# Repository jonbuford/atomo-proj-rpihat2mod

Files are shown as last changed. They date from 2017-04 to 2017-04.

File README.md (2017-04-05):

# atomo-proj-rpihat2mod
Raspberry Pi HAT Compatible 2 Module Designs

This design is using a KE02 44-pin microcontroller as an IO expander and stand-alone controller for a 2 IO module Atomo Controller Connector board. There are two versions, one with a 34-pin Power module and another that is only for powering by the Raspberry Pi.

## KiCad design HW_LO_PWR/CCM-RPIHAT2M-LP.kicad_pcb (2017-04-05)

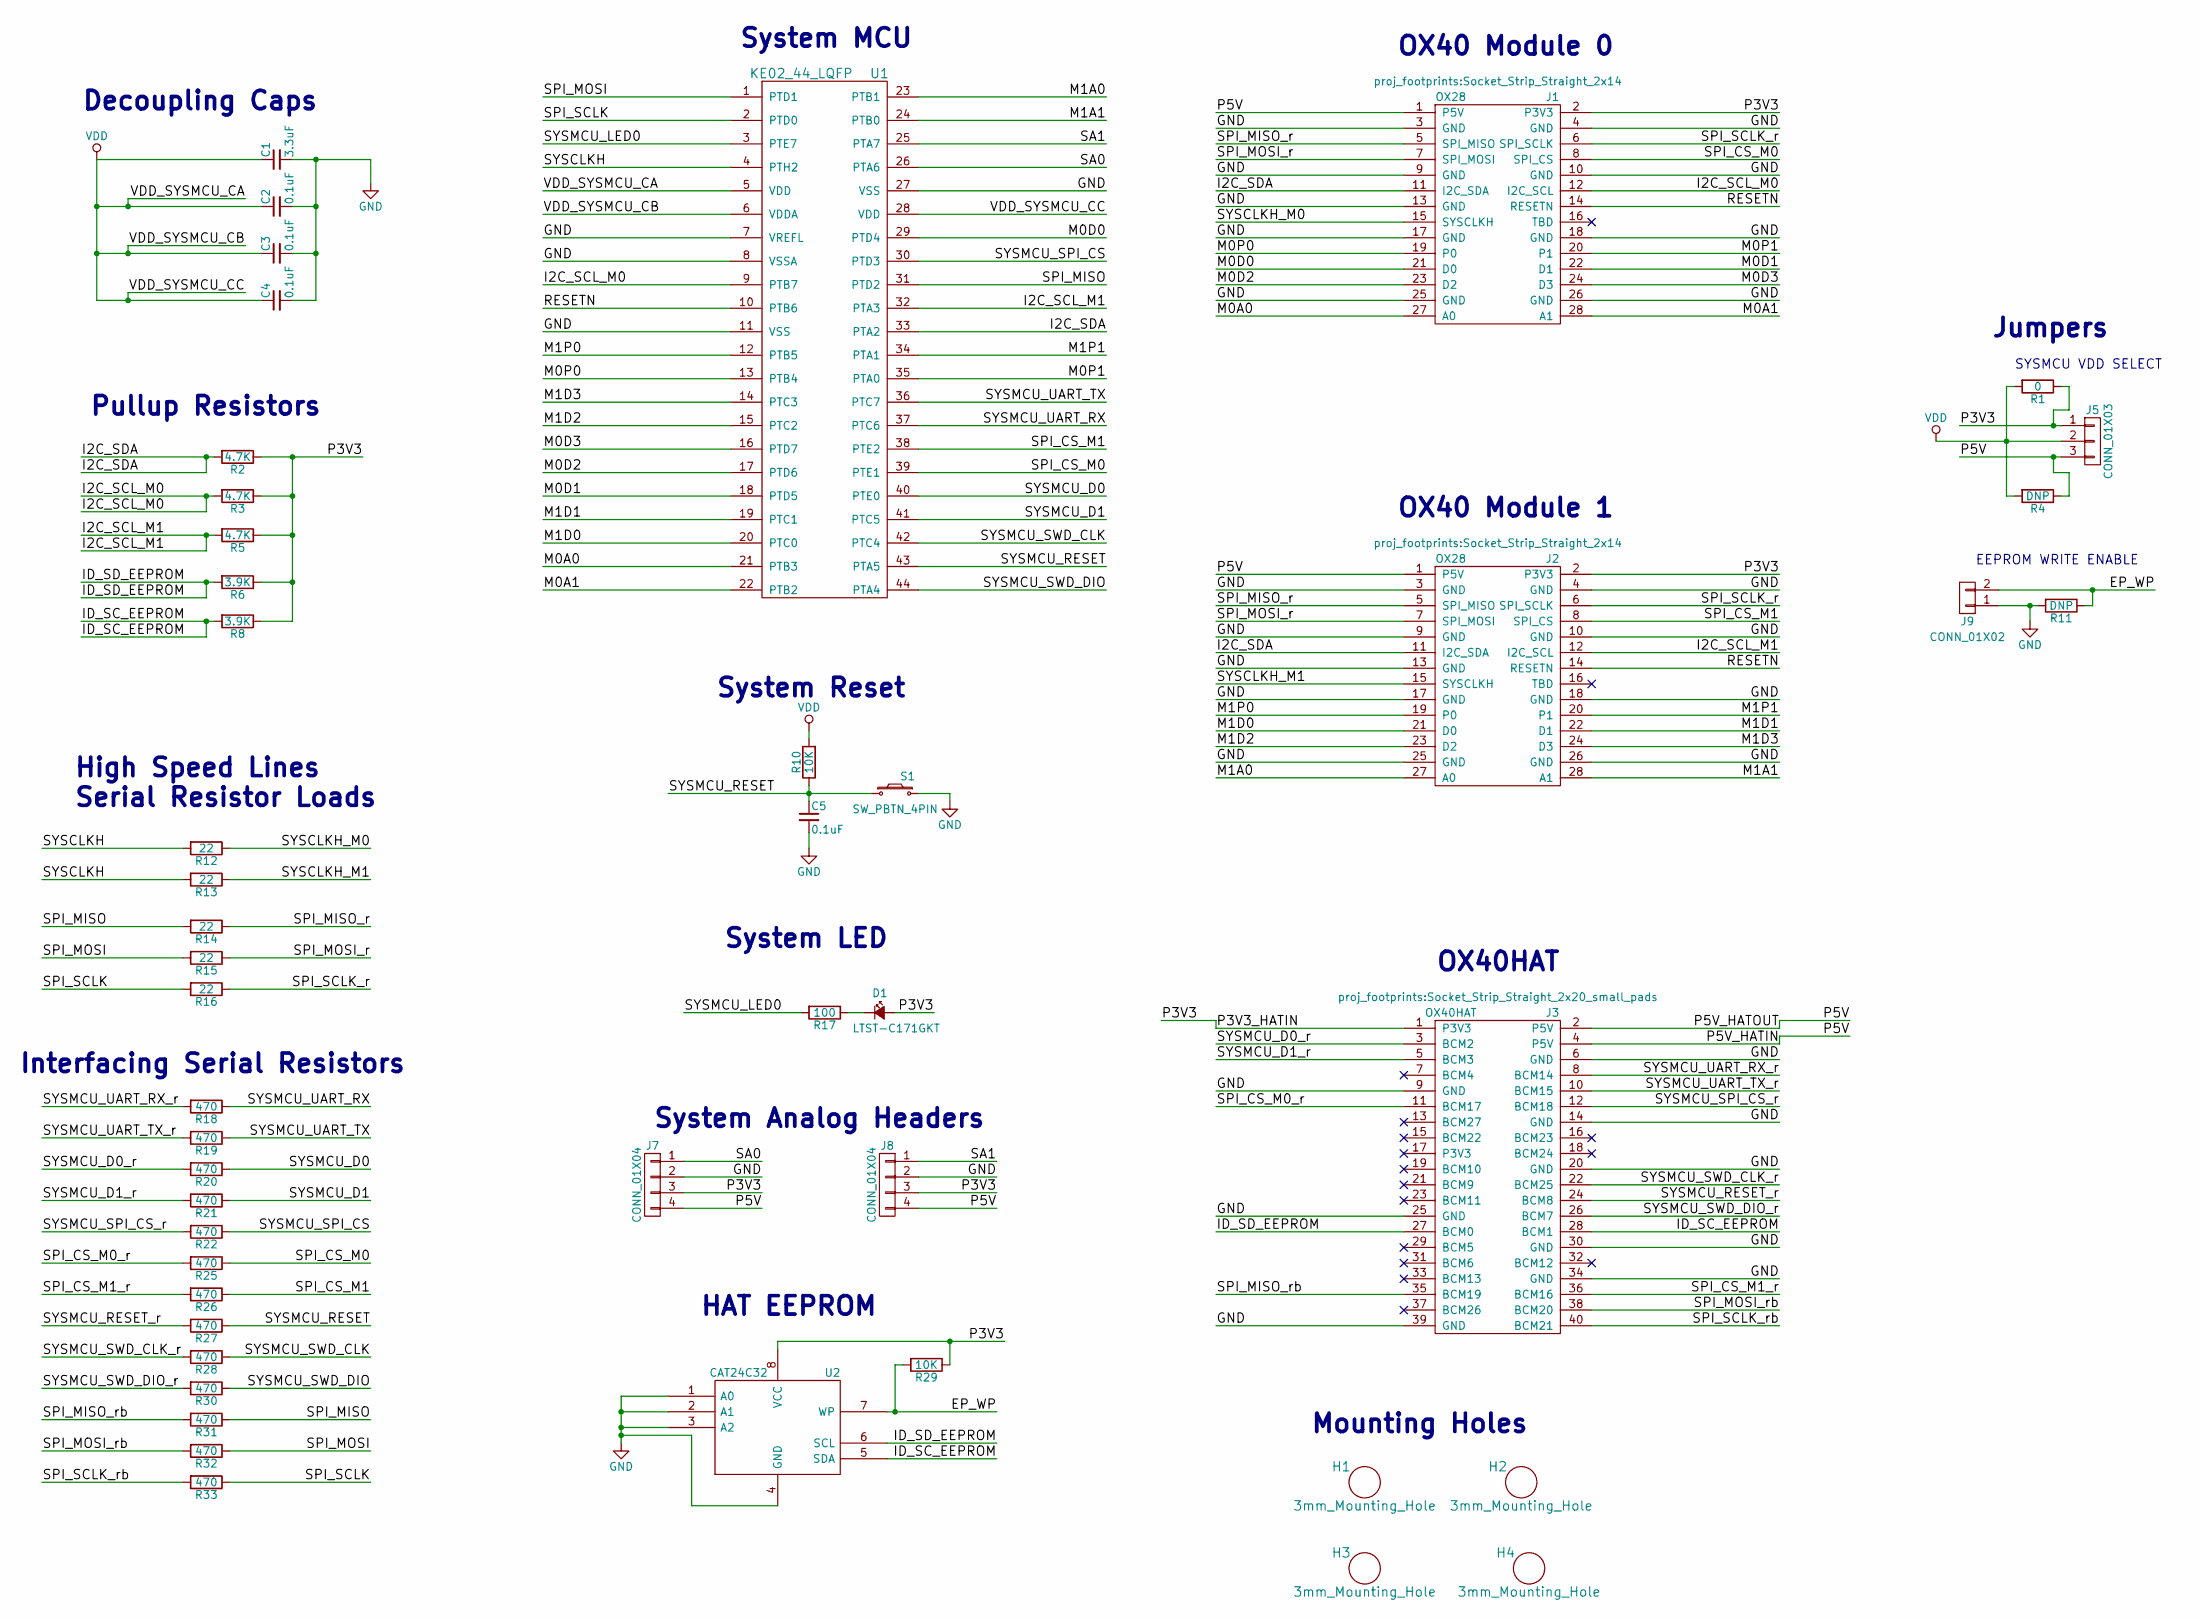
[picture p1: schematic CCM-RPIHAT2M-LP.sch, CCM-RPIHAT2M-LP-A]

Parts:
C1: 3.3uF; C_0603_HandSoldering; MPN GRM155R71H104ME14D
C2, C3, C4, C5: 0.1uF; C_0603_HandSoldering; MPN GRM155R71H104ME14D
D1: LTST-C171GKT; LED_0805
H1, H2, H3, H4: 3mm_Mounting_Hole; NPTH_3mm_ID
J1, J2: OX28; Socket_Strip_Straight_2x14
J3: OX40HAT; Socket_Strip_Straight_2x20_small_pads
J5: CONN_01X03; Pin_Header_Straight_1x03
J7, J8: CONN_01X04; Pin_Header_Straight_1x04
J9: CONN_01X02; Pin_Header_Straight_1x02
R1: 0; R_0805_HandSoldering; MPN RC0402JR-0722RL
R2, R3, R5: 4.7K; R_0603_HandSoldering; MPN RC0402JR-0722RL
R4, R11: DNP; R_0805_HandSoldering; MPN RC0402JR-0722RL
R6, R8: 3.9K; R_0603_HandSoldering; MPN RC0402JR-0722RL
R10, R29: 10K; R_0603_HandSoldering; MPN RC0402JR-0722RL
R12, R13, R14, R15, R16: 22; R_0603_HandSoldering; MPN RC0402JR-0722RL
R17: 100; R_0603_HandSoldering; MPN RC0402JR-0722RL
R18, R19, R20, R21, R22, R25, R26, R27, R28, R30, R31, R32, R33: 470; R_0603_HandSoldering; MPN RC0402JR-0722RL
S1: SW_PBTN_4PIN; SMT_6MM_Tact_SW
U1: KE02_44_LQFP; LQFP_44
U2: CAT24C32; SOIC-8

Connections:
/EP_WP: J9.2, R11.1, R29.2, U2.7 (WP)
/I2C_SCL_M0: J1.12 (I2C_SCL), R3.2, U1.9 (PTB7)
/I2C_SCL_M1: J2.12 (I2C_SCL), R5.2, U1.32 (PTA3)
/I2C_SDA: J1.11 (I2C_SDA), J2.11 (I2C_SDA), R2.2, U1.33 (PTA2)
/ID_SC_EEPROM: J3.28 (BCM1), R8.2, U2.5 (SDA)
/ID_SD_EEPROM: J3.27 (BCM0), R6.2, U2.6 (SCL)
/M0A0: J1.27 (A0), U1.21 (PTB3)
/M0A1: J1.28 (A1), U1.22 (PTB2)
/M0D0: J1.21 (D0), U1.29 (PTD4)
/M0D1: J1.22 (D1), U1.18 (PTD5)
/M0D2: J1.23 (D2), U1.17 (PTD6)
/M0D3: J1.24 (D3), U1.16 (PTD7)
/M0P0: J1.19 (P0), U1.13 (PTB4)
/M0P1: J1.20 (P1), U1.35 (PTA0)
/M1A0: J2.27 (A0), U1.23 (PTB1)
/M1A1: J2.28 (A1), U1.24 (PTB0)
/M1D0: J2.21 (D0), U1.20 (PTC0)
/M1D1: J2.22 (D1), U1.19 (PTC1)
/M1D2: J2.23 (D2), U1.15 (PTC2)
/M1D3: J2.24 (D3), U1.14 (PTC3)
/M1P0: J2.19 (P0), U1.12 (PTB5)
/M1P1: J2.20 (P1), U1.34 (PTA1)
/P3V3: D1.2 (A), J1.2 (P3V3), J2.2 (P3V3), J3.1 (P3V3), J5.1, J7.3, J8.3, R1.1, R2.1, R3.1, R5.1, R6.1, R8.1, R29.1, U2.8 (VCC)
/P5V: J1.1 (P5V), J2.1 (P5V), J3.2 (P5V), J3.4 (P5V), J5.3, J7.4, J8.4, R4.1
/RESETN: J1.14 (RESETN), J2.14 (RESETN), U1.10 (PTB6)
/SA0: J7.1, U1.26 (PTA6)
/SA1: J8.1, U1.25 (PTA7)
/SPI_CS_M0: J1.8 (SPI_CS), R25.1, U1.39 (PTE1)
/SPI_CS_M0_r: J3.11 (BCM17), R25.2
/SPI_CS_M1: J2.8 (SPI_CS), R26.1, U1.38 (PTE2)
/SPI_CS_M1_r: J3.36 (BCM16), R26.2
/SPI_MISO: R14.2, R31.1, U1.31 (PTD2)
/SPI_MISO_r: J1.5 (SPI_MISO), J2.5 (SPI_MISO), R14.1
/SPI_MISO_rb: J3.35 (BCM19), R31.2
/SPI_MOSI: R15.2, R32.1, U1.1 (PTD1)
/SPI_MOSI_r: J1.7 (SPI_MOSI), J2.7 (SPI_MOSI), R15.1
/SPI_MOSI_rb: J3.38 (BCM20), R32.2
/SPI_SCLK: R16.2, R33.1, U1.2 (PTD0)
/SPI_SCLK_r: J1.6 (SPI_SCLK), J2.6 (SPI_SCLK), R16.1
/SPI_SCLK_rb: J3.40 (BCM21), R33.2
/SYSCLKH: R12.2, R13.2, U1.4 (PTH2)
/SYSCLKH_M0: J1.15 (SYSCLKH), R12.1
/SYSCLKH_M1: J2.15 (SYSCLKH), R13.1
/SYSMCU_D0: R20.1, U1.40 (PTE0)
/SYSMCU_D0_r: J3.3 (BCM2), R20.2
/SYSMCU_D1: R21.1, U1.41 (PTC5)
/SYSMCU_D1_r: J3.5 (BCM3), R21.2
/SYSMCU_LED0: R17.2, U1.3 (PTE7)
/SYSMCU_RESET: C5.1, R10.1, R27.1, S1.1, S1.2, U1.43 (PTA5)
/SYSMCU_RESET_r: J3.24 (BCM8), R27.2
/SYSMCU_SPI_CS: R22.1, U1.30 (PTD3)
/SYSMCU_SPI_CS_r: J3.12 (BCM18), R22.2
/SYSMCU_SWD_CLK: R28.1, U1.42 (PTC4)
/SYSMCU_SWD_CLK_r: J3.22 (BCM25), R28.2
/SYSMCU_SWD_DIO: R30.1, U1.44 (PTA4)
/SYSMCU_SWD_DIO_r: J3.26 (BCM7), R30.2
/SYSMCU_UART_RX: R18.1, U1.37 (PTC6)
/SYSMCU_UART_RX_r: J3.8 (BCM14), R18.2
/SYSMCU_UART_TX: R19.1, U1.36 (PTC7)
/SYSMCU_UART_TX_r: J3.10 (BCM15), R19.2
GND: C1.2, C2.2, C3.2, C4.2, C5.2, J1.3 (GND), J1.4 (GND), J1.9 (GND), J1.10 (GND), J1.13 (GND), J1.17 (GND), J1.18 (GND), J1.25 (GND), J1.26 (GND), J2.3 (GND), J2.4 (GND), J2.9 (GND), J2.10 (GND), J2.13 (GND), J2.17 (GND), J2.18 (GND), J2.25 (GND), J2.26 (GND), J3.6 (GND), J3.9 (GND), J3.14 (GND), J3.20 (GND), J3.25 (GND), J3.30 (GND), J3.34 (GND), J3.39 (GND), J7.2, J8.2, J9.1, R11.2, S1.3, S1.4, U1.7 (VREFL), U1.8 (VSSA), U1.11 (VSS), U1.27 (VSS), U2.1 (A0), U2.2 (A1), U2.3 (A2), U2.4 (GND)
unnamed: D1.1 (K), R17.1
VDD: C1.1, C2.1, C3.1, C4.1, J5.2, R1.2, R4.2, R10.2, U1.5 (VDD), U1.6 (VDDA), U1.28 (VDD)

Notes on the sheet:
OX40 Module 1
OX40 Module 0
Decoupling Caps
Jumpers
SYSMCU VDD SELECT
EEPROM WRITE ENABLE
Pullup Resistors
HAT EEPROM
System Analog Headers
System LED
System Reset
Interfacing Serial Resistors
High Speed Lines Serial Resistor Loads
Mounting Holes
OX40HAT
System MCU

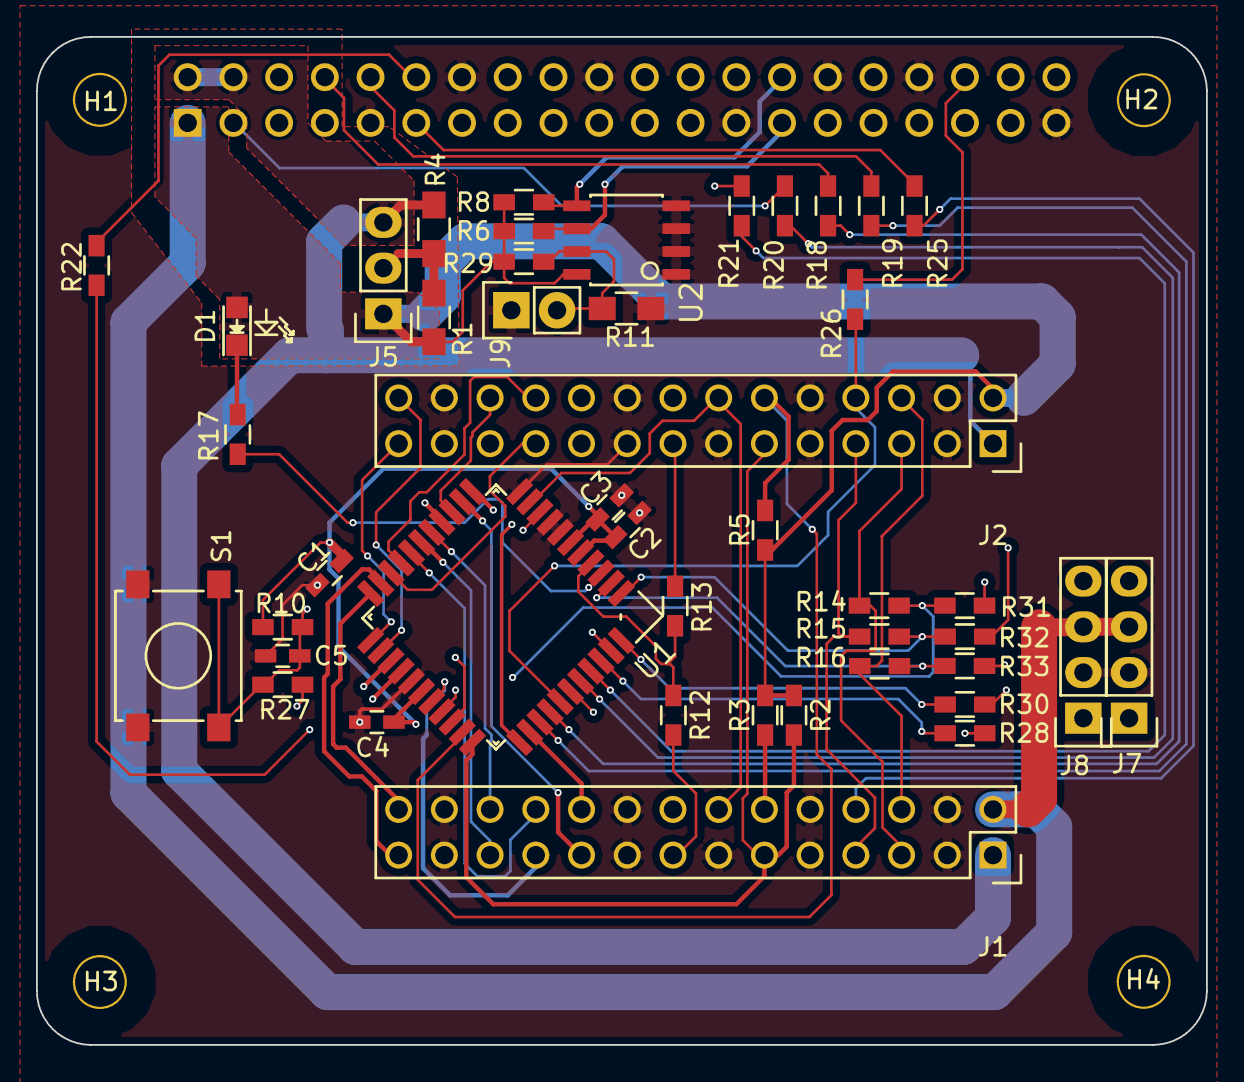
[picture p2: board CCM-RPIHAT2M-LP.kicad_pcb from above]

Board: 4 copper layers, 65.0 x 56.0 mm, 49 parts (1 on the bottom side), 63 nets.
